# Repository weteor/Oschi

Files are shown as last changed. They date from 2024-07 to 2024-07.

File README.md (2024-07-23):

### oschi

a orthogonal le chiffre-esk keyboard with hummingbird style alpha options

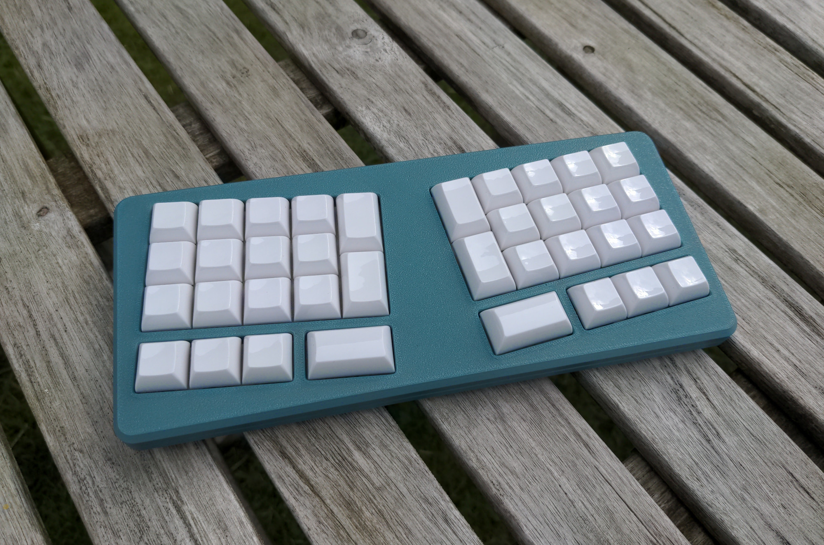
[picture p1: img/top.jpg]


## Features

- MX-Hotswap sockets
- CH552T Controller (w/ FAK firmware)
- gerber and case files are supplied (kicad files, stl as well as cadquery files)
- completely open source, permissive license ([CERN-OHL-P](https://cern-ohl.web.cern.ch/home))

##### layout options

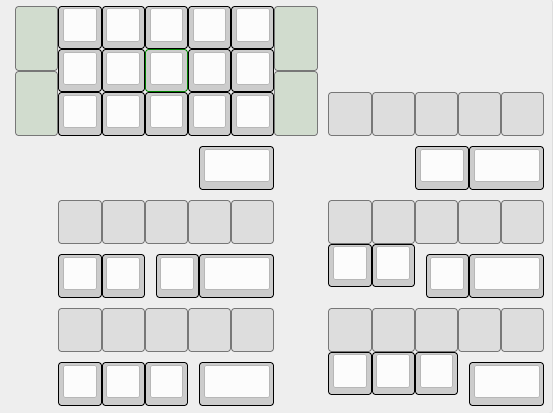
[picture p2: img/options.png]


make sure to grab the right combinations of plate and case top.

## Want one?

All production files you need to build your own board can be found [here](./prod/).

Apart from the pcb and optionally a case you need:

- 38 hotswap sockets

- 38 diodes (1N4148 int SOT-123)

- 38 of your favourite switches

- 1x CH552T (TSSOP-20)

- 1x USBLC6-2SC6 (SOT-23-6)

- 1x 10kOhm resistor (SMD 0603)

- 2x 5.1kOhm resistors (SMD 0603)

- 2x 100nF capacitors (SMD 0603)

- 1x USB Connector C-Type, 12 pin/16pin

### firmware

Config for FAK can be found [here](https://github.com/weteor/fak-config/tree/main/keyboards/oschi). Please also see [FAK-Firmware site](https://github.com/semickolon/fak) for more information

Bootloader should be available on plugin until firmware is written. After that either use the firmware BOOT to go into bootloader, or hold the boot button on the pcb pressed while pluggin in the usb cable.

### the rest

Everything in this repository is free to use however you might see fit. If you want to support me and my projects, please consider linking back to this repository if you build/change/use anything.

If you would like to send me a tip, you could do it [here](https://ko-fi.com/weteor) (Please don't feel like you have to).

### more pictures

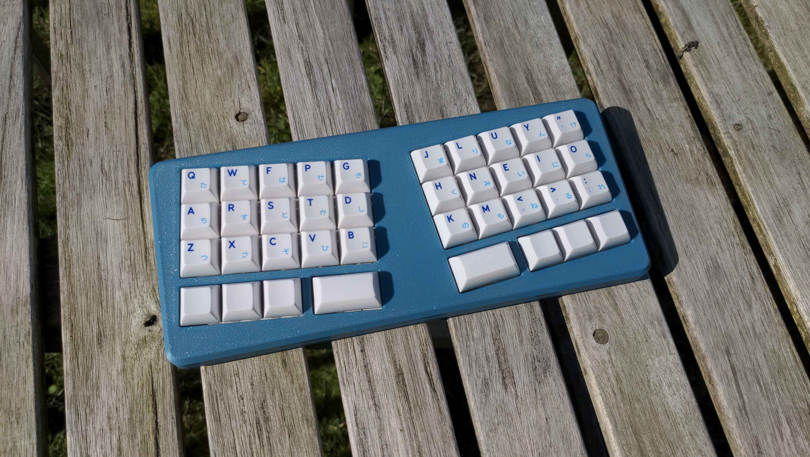
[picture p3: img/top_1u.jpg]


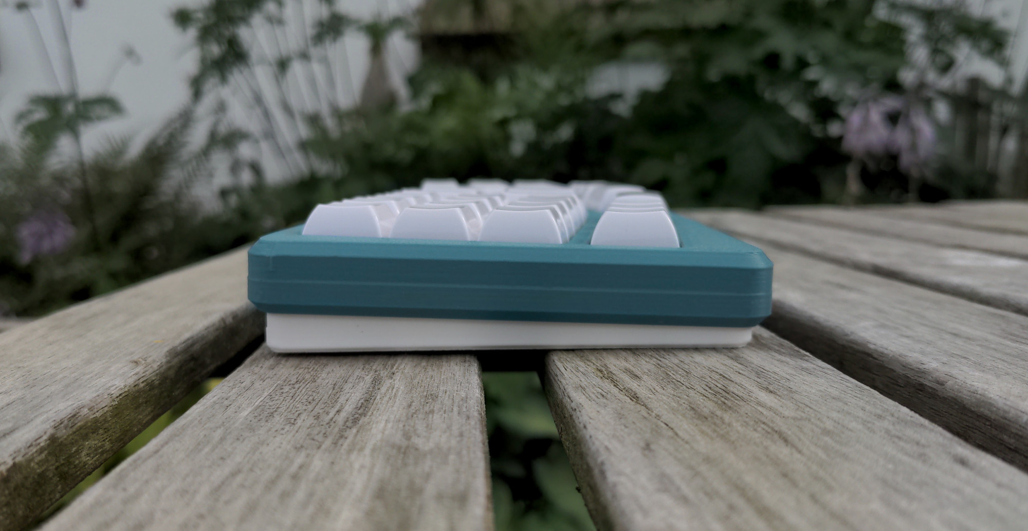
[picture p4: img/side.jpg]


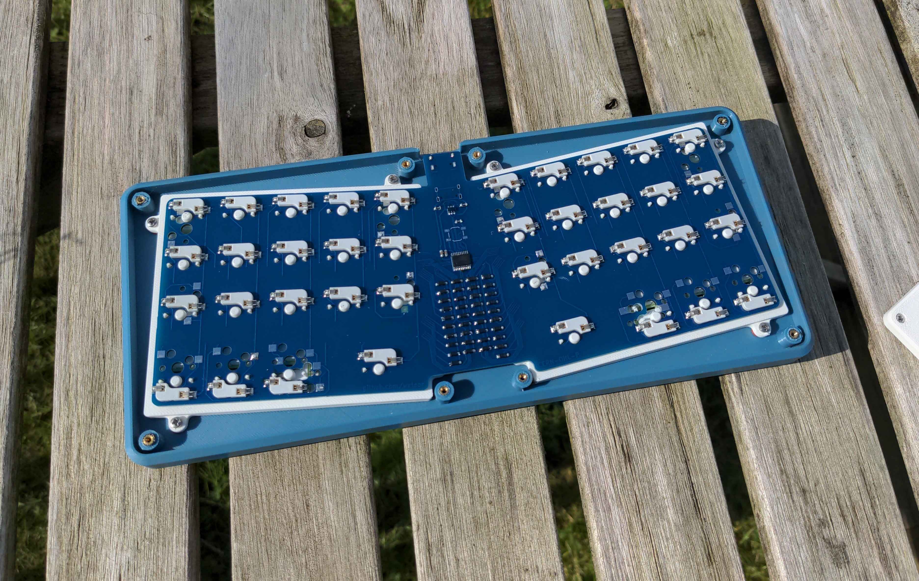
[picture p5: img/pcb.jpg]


---

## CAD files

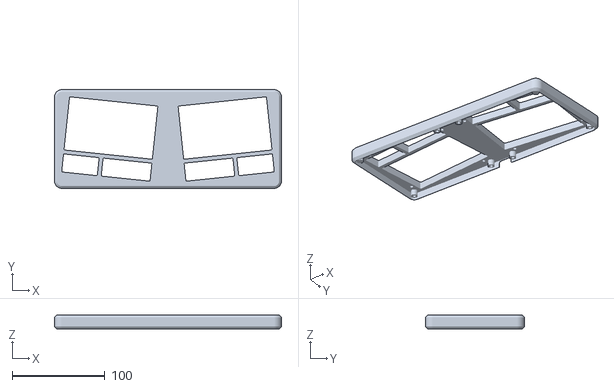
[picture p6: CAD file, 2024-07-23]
prod/Case/oschi_case_top_2u_offset.stl
244.7 x 106.5 x 15.0

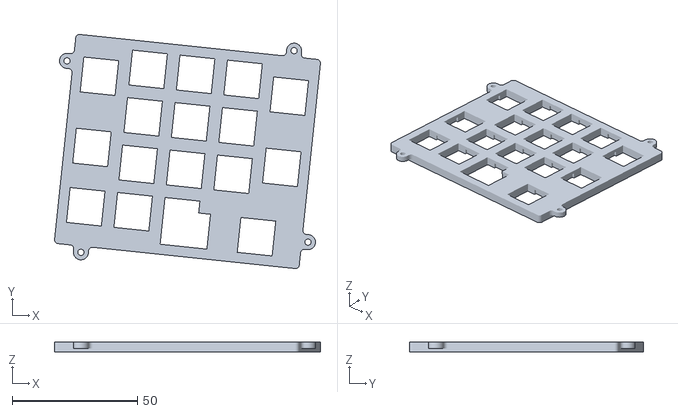
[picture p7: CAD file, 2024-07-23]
prod/Plates/oschi_plate_no_offset_left_1.5u_inner_outer.stl
106.2 x 93.5 x 4.00

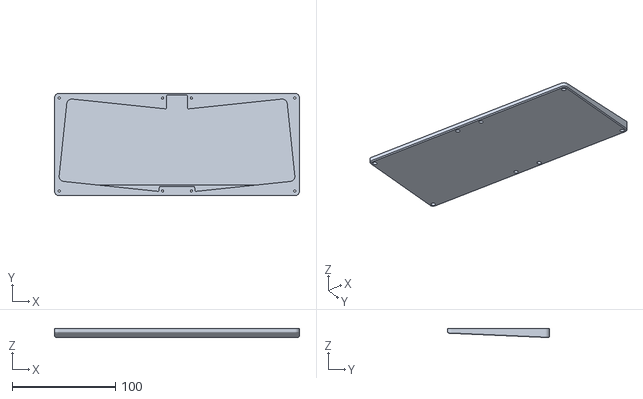
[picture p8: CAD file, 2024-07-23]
prod/Case/oschi_case_bottom.stl
237.2 x 99.0 x 8.92

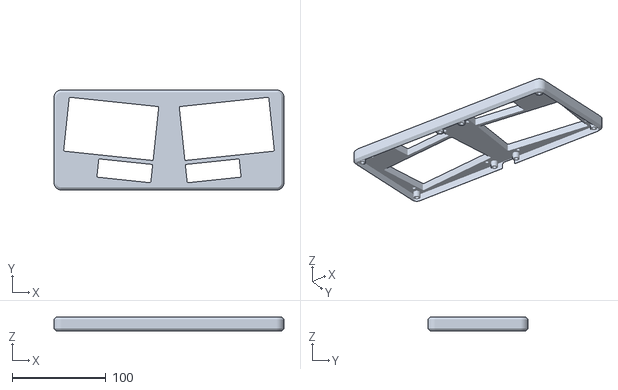
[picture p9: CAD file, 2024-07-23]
prod/Case/oschi_case_top_1.75u_1.25u.stl
244.7 x 106.5 x 15.0

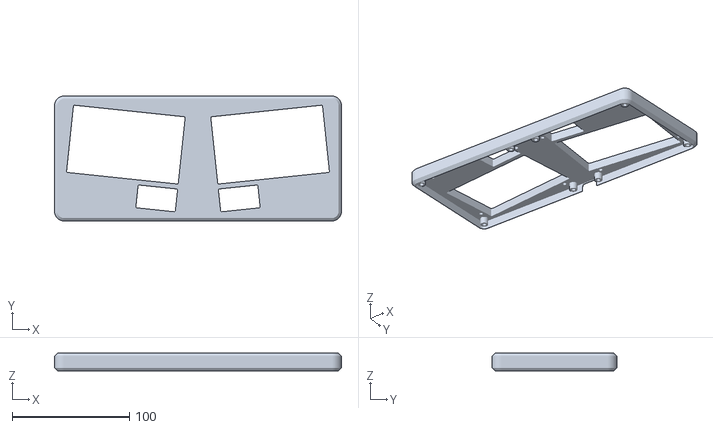
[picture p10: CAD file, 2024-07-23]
prod/Case/oschi_case_top_1.75u_only.stl
244.7 x 106.5 x 15.0

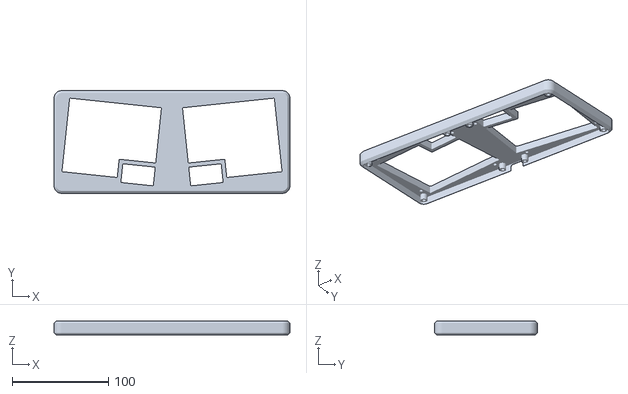
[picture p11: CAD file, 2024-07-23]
prod/Case/oschi_case_top_3u_no_offset.stl
244.7 x 106.5 x 15.0

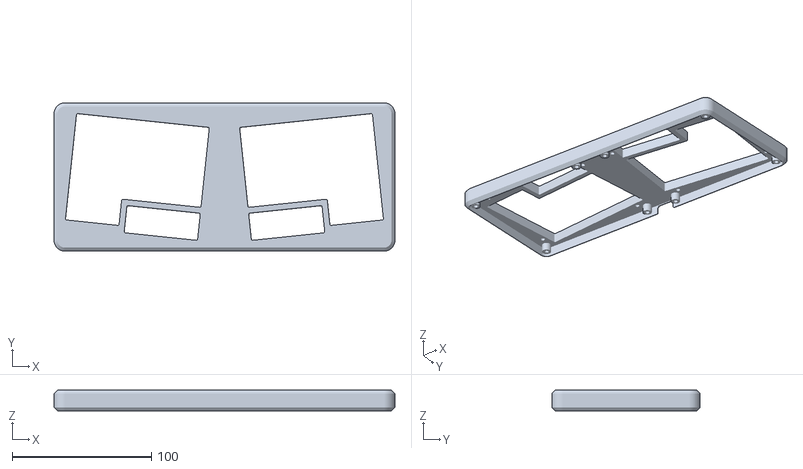
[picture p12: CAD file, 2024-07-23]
prod/Case/oschi_case_top_2u_no_offset.stl
244.7 x 106.5 x 15.0

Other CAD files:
prod/Case/oschi_case_top_3u_offset.stl
prod/Plates/oschi_plate_offset_right_1.5u_inner.stl
prod/Plates/oschi_plate_no_offset_right_1.5u_inner.stl
prod/Plates/oschi_plate_offset_left_1.5u_inner.stl
prod/Plates/oschi_plate_offset_right.stl
prod/Plates/oschi_plate_no_offset_left.stl
prod/Plates/oschi_plate_offset_right_1.5u_inner_outer.stl
prod/Case/oschi_case_top_1.75u_1u.stl
prod/Plates/oschi_plate_no_offset_right.stl
prod/Plates/oschi_plate_offset_left.stl
prod/Plates/oschi_plate_offset_left_1.5u_inner_outer.stl
prod/Plates/oschi_plate_no_offset_left_1.5u_inner.stl
prod/Plates/oschi_plate_no_offset_right_1.5u_inner_outer.stl

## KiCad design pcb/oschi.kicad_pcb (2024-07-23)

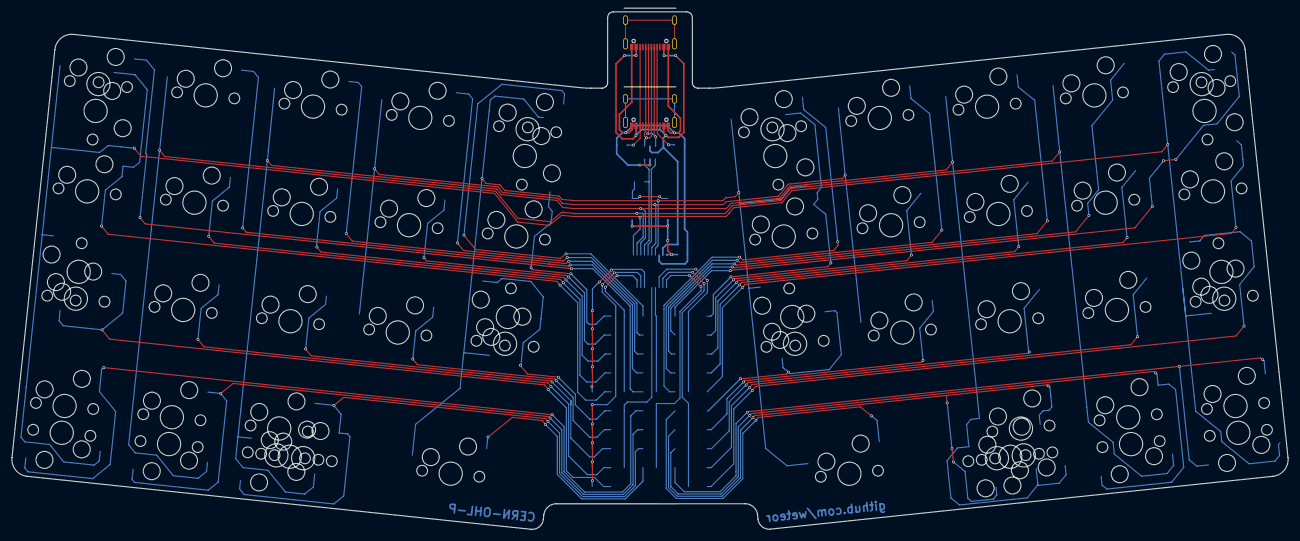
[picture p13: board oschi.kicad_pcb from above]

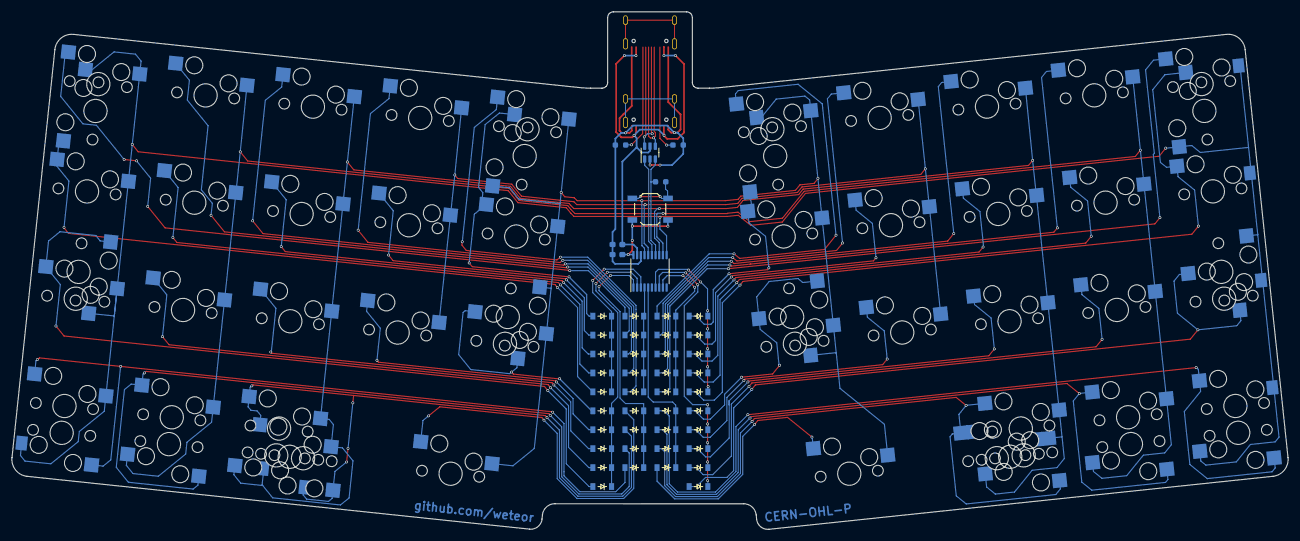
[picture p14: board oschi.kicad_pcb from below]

Board: 2 copper layers, 225.3 x 91.4 mm, 104 parts (46 on the bottom side), 61 nets.

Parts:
C1, C2: 100nF; C_0603_HandSolder
D1, D2, D3, D4, D5, D6, D7, D8, D9, D10, D11, D12, D13, D14, D15, D16, D17, D18, D19, D20, D21, D22, D23, D24, D25, D26, D27, D28, D29, D30, D31, D32, D33, D34, D35, D36, D37, D38: D; D_SOD-123
J1, J2: USB_C_Receptacle_USB2.0; USB C-31-M-12
R1, R2: 5.1k; R_0603_HandSolder
R3: 10k; R_0603_HandSolder
SW1, SW2, SW3, SW4, SW5, SW6, SW7, SW8, SW9, SW10, SW11, SW12, SW13, SW14, SW15, SW17, SW18, SW19, SW20, SW21, SW22, SW24, SW25, SW26, SW29, SW30, SW31, SW32, SW33, SW34, SW35, SW36, SW37, SW39, SW40, SW41, SW42, SW43, SW44, SW45, SW46, SW47, SW56, SW57: SW_Push; CherryMX_Hotswap_3d
SW16, SW38: SW_Push; CherryMX_Hotswap_1.25u
SW23, SW27: SW_Push; CherryMX_Hotswap_1.75u_3d
SW28: BOOT; SW_SPST_TL3342
SW48, SW49, SW50, SW51, SW52, SW53, SW54, SW55: SW_Push; CherryMX_Hotswap_1.5u
U1: USBLC6-2SC6; SOT-23-6
U2: TSSOP-20_4.4x6.5mm_P0.65mm

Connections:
+3.3V: C1.1, SW28.2, U2.20 (V33)
BOOT: R3.2, SW28.1
CC1: J1.A5 (CC1), J2.A5 (CC1), R1.1
CC2: J1.B5 (CC2), J2.B5 (CC2), R2.1
Col_1: SW1.1, SW2.1, SW3.1, SW4.1, SW44.1, SW45.1, SW46.1, SW47.1, SW52.2, SW53.2, SW54.1, SW55.1, SW56.1, SW57.1, U2.11 (P3.3)
Col_2: SW5.1, SW6.1, SW7.1, SW8.1, SW9.1, SW39.1, SW40.1, SW41.1, SW42.1, SW43.1, U2.12 (P3.4)
Col_3: SW10.1, SW11.1, SW12.1, SW13.1, SW14.1, SW15.1, SW16.1, SW32.1, SW33.1, SW34.1, SW35.1, SW36.1, SW37.1, SW38.1, U2.13 (P3.5)
Col_4: SW17.1, SW18.1, SW19.1, SW29.1, SW30.1, SW31.1, U2.16 (P1.3)
Col_5: SW20.1, SW21.1, SW22.1, SW23.1, SW24.1, SW25.1, SW26.1, SW27.1, SW48.1, SW49.1, SW50.2, SW51.2, U2.17 (P1.2)
GND: C1.2, C2.2, J1.A1 (GND), J1.A12 (GND), J1.B1 (GND), J1.B12 (GND), J2.A1 (GND), J2.A12 (GND), J2.B1 (GND), J2.B12 (GND), R1.2, R2.2, U1.2 (GND), U2.18 (GND)
unnamed: D1.2 (A), SW1.2, SW52.1
unnamed: D2.2 (A), SW2.2, SW53.1
unnamed: D3.2 (A), SW3.2, SW4.2
unnamed: D4.2 (A), SW5.2
unnamed: D5.2 (A), SW6.2
unnamed: D6.2 (A), SW7.2
unnamed: D7.2 (A), SW8.2, SW9.2
unnamed: D8.2 (A), SW10.2
unnamed: D9.2 (A), SW11.2
unnamed: D10.2 (A), SW12.2
unnamed: D11.2 (A), SW13.2, SW14.2, SW15.2, SW16.2
unnamed: D12.2 (A), SW17.2
unnamed: D13.2 (A), SW18.2
unnamed: D14.2 (A), SW19.2
unnamed: D15.2 (A), SW20.2
unnamed: D16.2 (A), SW21.2, SW48.2
unnamed: D17.2 (A), SW22.2, SW49.2
unnamed: D18.2 (A), SW23.2
unnamed: D19.2 (A), SW24.2
unnamed: D20.2 (A), SW25.2, SW50.1
unnamed: D21.2 (A), SW26.2, SW51.1
unnamed: D22.2 (A), SW27.2
unnamed: D23.2 (A), SW29.2
unnamed: D24.2 (A), SW30.2
unnamed: D25.2 (A), SW31.2
unnamed: D26.2 (A), SW32.2
unnamed: D27.2 (A), SW33.2
unnamed: D28.2 (A), SW34.2
unnamed: D29.2 (A), SW35.2, SW36.2, SW37.2, SW38.2
unnamed: D30.2 (A), SW39.2
unnamed: D31.2 (A), SW40.2
unnamed: D32.2 (A), SW41.2
unnamed: D33.2 (A), SW42.2, SW43.2
unnamed: D34.2 (A), SW44.2, SW54.2
unnamed: D35.2 (A), SW45.2, SW55.2
unnamed: D36.2 (A), SW46.2, SW47.2
unnamed: D37.2 (A), SW56.2
unnamed: D38.2 (A), SW57.2
PORT+: J1.A6 (D+), J1.B6 (D+), J2.A6 (D+), J2.B6 (D+), U1.4 (I/O2)
PORT-: J1.A7 (D-), J1.B7 (D-), J2.A7 (D-), J2.B7 (D-), U1.6 (I/O1)
Row_1: D4.1 (K), D8.1 (K), D12.1 (K), D15.1 (K), D37.1 (K), U2.9 (P3.1)
Row_2: D1.1 (K), D5.1 (K), D9.1 (K), D13.1 (K), D16.1 (K), U2.7 (P1.0)
Row_3: D2.1 (K), D6.1 (K), D10.1 (K), D14.1 (K), D17.1 (K), U2.8 (P1.1)
Row_4: D3.1 (K), D7.1 (K), D11.1 (K), D18.1 (K), U2.5 (P1.7)
Row_5: D19.1 (K), D23.1 (K), D26.1 (K), D30.1 (K), D38.1 (K), U2.4 (P1.6)
Row_6: D20.1 (K), D24.1 (K), D27.1 (K), D31.1 (K), D34.1 (K), U2.3 (P1.5)
Row_7: D21.1 (K), D25.1 (K), D28.1 (K), D32.1 (K), D35.1 (K), U2.2 (P1.4)
Row_8: D22.1 (K), D29.1 (K), D33.1 (K), D36.1 (K), U2.1 (P3.2)
UDM: U1.1 (I/O1), U2.15 (P3.7)
UDP: R3.1, U1.3 (I/O2), U2.14 (P3.6)
VBUS: C2.1, J1.A4 (VBUS), J1.A9 (VBUS), J1.B4 (VBUS), J1.B9 (VBUS), J2.A4 (VBUS), J2.A9 (VBUS), J2.B4 (VBUS), J2.B9 (VBUS), U1.5 (VBUS), U2.19 (VCC)

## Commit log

2024-07-23 add pcb
    [oschi.kicad_pcb, oschi.kicad_sch]
2024-07-23 add case
2024-07-23 add prod data
    [oschi_case_bottom.stl, oschi_case_top_1.75u_1.25u.stl, oschi_case_top_1.75u_1u.stl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]
